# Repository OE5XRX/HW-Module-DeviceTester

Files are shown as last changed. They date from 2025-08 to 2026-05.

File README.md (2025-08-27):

# HW-Module-DeviceTester

## License

This project is licensed under [CERN-OHL-S-2.0](https://choosealicense.com/licenses/cern-ohl-s-2.0/).

## Badges

<br>
<br>
<br>
<br>
<br>

## Contact

OE5XRX Amateur Radio Club<br>
🌐 https://oe5xrx.org<br>
✉️ info@oe5xrx.org<br>

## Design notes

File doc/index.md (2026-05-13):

---
title: Device Tester
nav_order: 1
parent: Hardware
description: Bringup und Test-Board für die OE5XRX-Hardware-Module — Standalone-Modul-Test, BusBoard-Test ohne eigene Versorgung, CM4-Flash via rpiboot.
---

# Device Tester PCB

<table>
  <tr><th>Top</th><th>Bottom</th></tr>
  <tr>
    <td>top</td>
    <td>bottom</td>
  </tr>
</table>

## Übersicht

Universelles Bringup- und Test-Board für alle OE5XRX-Hardware-Module. Es hat zwei voneinander unabhängige Steckverbinder-Seiten und kombiniert sie mit USB-C-PC-Anschlüssen, einer +12V-Schraubterminal-Quelle und einem 4-Pin-Flash-Header für CM4-rpiboot:

- **Device-Tester-Seite** (`J203`, männlicher PCN10-Stecker — wie ein BusBoard-Slot): Hier wird ein zu testendes Modul (PowerBoard, CM4Carrier, FM-Transceiver etc.) eingesteckt. Das Modul wird vom DeviceTester aus mit Strom versorgt — USB-C `J201` bringt +5V_A; Phoenix-Schraubterminal `J101` bringt +12V (für Module die echte +12V brauchen, z.B. FM-Modul mit SA818-TX-Spitzen).
- **Bus-Tester-Seite** (`J302`, weibliche PCN10C-Buchse — wie ein Modul): Hier wird ein zu testendes BusBoard angesteckt. USB-C `J301` bringt +5V_B und kann über Jumper `J303` an die Bus-Tester-Seite durchgereicht werden, sodass das BusBoard ohne eigenes PowerBoard betrieben werden kann.
- **CM4 flashen**: Über den 4-Pin Flash-Header `J202` werden die beiden Bus-Pins `nRPIBOOT` und `USB_OTG_ID` manuell per Jumper auf die richtigen Pegel gezogen — siehe ["CM4 flashen"](#cm4-flashen) unten.

Die zwei +5V-Rails (`+5V_A` Device-Seite, `+5V_B` Bus-Seite) sind elektrisch entkoppelt, damit kein Backfeed zwischen den Test-Kontexten passiert.

## Block-Diagramm

```mermaid
flowchart LR
    USBCa["USB-C J201<br/>(Device-Seite)"] -->|"+5V_A"| RailA[/+5V_A/]
    Phoenix["Schraubterminal J101<br/>+12V"] --> Rail12[/+12V/]
    USBCb["USB-C J301<br/>(Bus-Seite)"] -->|"+5V_B"| RailB[/+5V_B/]

    RailA --> J203["J203 PCN10-20P (male)<br/>Device Tester Connector"]
    Rail12 --> J203
    RailA --> J202["J202 4-Pin Flash-Header<br/>(rpiboot Jumper)"]

    RailB -.->|"J303 Jumper<br/>(optional)"| J302
    J302["J302 PCN10C-20S (female)<br/>Bus Tester Connector"]

    J203 -->|"USB+/-"| USBCa
    J302 -->|"USB+/-"| USBCb
    J202 -.->|"nRPIBOOT, USB_OTG_ID"| J203

    DUT[Device Under Test<br/>Modul] -.->|"steckt in"| J203
    BB[BusBoard Under Test] -.->|"steckt in"| J302
```

## Steckverbinder

| Bezeichner | Typ | Funktion |
| --- | --- | --- |
| **J101** | Phoenix MKDS-1,5-2 5.08 mm Schraubterminal (2-Pin) | +12V-Eingang. Nötig für Module die echte +12V brauchen (z.B. SA818-TX). |
| **J201** | USB-C 2.0 (G-Switch GT-USB-7010ASV) | Device-Seite. +5V_A-Versorgung und USB-Datenanschluss für den DUT in `J203`. |
| **J202** | 4-Pin Stiftleiste 2.54 mm | Flash-Header: GND / nRPIBOOT / USB_OTG_ID / +5V_A. Silkscreen-beschriftet. |
| **J203** | Hirose **PCN10-20P-2.54DS** (männlich, 2×10) | "Device Tester Connector" — Slot in den der DUT eingesetzt wird. Pinbelegung entspricht der BusBoard-Slot-Seite. |
| **J301** | USB-C 2.0 (G-Switch GT-USB-7010ASV) | Bus-Seite. +5V_B-Versorgung und USB-Datenanschluss für eine angeschlossene BusBoard. |
| **J302** | Hirose **PCN10C-20S-2.54DS** (weiblich, 2×10) | "Bus Tester Connector" — Buchse die in einen BusBoard-Slot gesteckt wird. Pinbelegung wie ein normaler Modul-Stecker. |
| **J303** | 2-Pin Stiftleiste 2.54 mm | Jumper: schließt `+5V_B` auf die `+5V`-Pins von `J302`. Bei externer Bus-Versorgung **offen** lassen. |

## Versorgung (drei Rails)

| Rail | Quelle | Funktion | Status-LED |
| ---- | --- | --- | --- |
| **+12V** | Schraubterminal `J101` | Speist den DUT in `J203` (+12V-Pins des PCN10-Steckers) | `D101` |
| **+5V_A** | USB-C `J201` (VBUS) | Speist `J203` (+5V-Pins) und `J202` Pin 4. Auch USB-Daten zum DUT laufen über `J201`. | `D201` |
| **+5V_B** | USB-C `J301` (VBUS) | Speist `J302` (+5V-Pins) **nur wenn Jumper `J303` geschlossen**. USB-Daten zur BusBoard laufen über `J301`. | `D301` |

Hinweis: `+12V` (`J101`) und `+5V_A` (`J201` VBUS) sind unabhängige Quellen. Beide können zusammen oder einzeln versorgt werden — der DUT zieht aus jeder Quelle was er braucht.

## CM4 flashen

Der CM4-Carrier hat keinen eigenen rpiboot-Jumper — beide Steuersignale (`nRPIBOOT` und `USB_OTG_ID`) sind auf den Bus-Stecker geführt. Hier am DeviceTester werden sie über den 4-Pin Flash-Header `J202` manuell per Jumper auf die korrekten Pegel gezogen:

| Pin | Signal |
|----:|---|
| 1 | GND |
| 2 | `nRPIBOOT` (geht via `J203 b2` zum CM4) |
| 3 | `USB_OTG_ID` (geht via `J203 b3` zum CM4) |
| 4 | +5V_A |

Jumper-Konfiguration für rpiboot-Mode:

- **Pin 1 ↔ 2** (GND ↔ nRPIBOOT) — versetzt den CM4 nach Power-Up in den USB-Boot-Modus.
- **Pin 3 ↔ 4** (USB_OTG_ID ↔ +5V_A) — schaltet die CM4-USB-Schnittstelle in den Device-Mode (PC = Host, CM4 = Peripheral).

Ablauf:

1. CM4 in den [CM4-Carrier](../HW-Module-CM4Carrier/) einsetzen, Carrier in den DeviceTester `J203` einstecken.
2. Beide Jumper auf `J202` setzen (1↔2 + 3↔4).
3. `J201` USB-C mit dem PC verbinden.
4. `rpiboot` auf dem PC starten — der CM4 erscheint als USB-Mass-Storage-Device (eMMC-Variante).
5. Nach dem Flashen: **beide Jumper wieder abziehen**, sonst bleibt der Carrier beim nächsten Power-Up im rpiboot-Mode hängen statt regulär zu booten.

## Test-Workflows

### 1. DUT-Test (Standalone-Modul-Bringup)

Use Case: ein einzelnes Modul (z.B. FM-Transceiver oder PowerBoard) **ohne** vollständige Remote-Station-Umgebung testen oder debuggen.

1. Modul in `J203` (Device Tester Connector) einsetzen.
2. +12V an `J101` anschließen falls das Modul +12V braucht (z.B. FM-Transceiver wegen SA818).
3. `J201` USB-C mit dem PC verbinden — versorgt das Modul mit +5V_A und macht dessen USB-Datenleitungen am PC sichtbar.
4. Tests/Bringup wie in der Doku des jeweiligen Moduls beschrieben (siehe `Bringup`-Sektionen der Modul-Docs).

### 2. CM4 flashen (rpiboot)

Siehe Sektion ["CM4 flashen"](#cm4-flashen) oben.

### 3. BusBoard-Test ohne eigene Versorgung

Use Case: eine BusBoard testen ohne komplettes PowerBoard angeschlossen zu haben — der DeviceTester speist das BusBoard direkt aus USB-C.

1. DeviceTester via `J302` (Bus Tester Connector — die weibliche Buchse) in einen freien Slot der zu testenden BusBoard stecken.
2. **`J303` Jumper schließen** — verbindet `+5V_B` mit den `+5V`-Pins von `J302`, sodass das BusBoard aus dem USB-C versorgt wird.
3. `J301` USB-C mit dem PC verbinden.
4. Falls das BusBoard ihr eigenes PowerBoard hat → `J303` Jumper **offen** lassen, sonst gibt's Backfeed-Risiko zwischen den zwei +5V-Quellen.

## Bringup des DeviceTester selbst

Nach Bestückung:

1. **+12V-Sanity:** Strombegrenztes Labornetzgerät (12 V / 100 mA) an `J101` anschließen → `D101` muss leuchten. Strom < 5 mA erwartet (nur LED + ihre Vorwiderstände).
2. **+5V_A-Sanity:** USB-C-Kabel an `J201` und einen USB-Host (PC oder Powerbank) → `D201` muss leuchten.
3. **+5V_B-Sanity:** USB-C-Kabel an `J301` → `D301` muss leuchten.
4. **+12V am DUT-Konnektor:** zwischen `J203`-Pins messen — die +12V-Pins müssen die Eingangsspannung zeigen.
5. **+5V_B-Isolation:** `J303` offen, `J301` versorgt — zwischen `J302`-Pin-+5V und GND messen → muss **0 V** zeigen. `J303` schließen → +5V_B muss durchschlagen.

## Verwandte Module

- [BusBoard](../HW-Module-BusBoard/) — kann via Bus-Tester-Seite (`J302`) ohne eigenes PowerBoard getestet werden.
- [CM4 Carrier](../HW-Module-CM4Carrier/) — wird via Device-Tester-Seite (`J203`) geflasht; rpiboot-Logik im DeviceTester (`J202`).
- [PowerBoard](../HW-Module-PowerBoard/) — kann standalone via Device-Tester-Seite (`J203` + Phoenix `J101` für +12V) getestet werden.
- [FM Transceiver](../HW-Module-FMTransceiver/) — Standalone-Bringup via Device-Tester-Seite (braucht beide Quellen: USB-C für USB + +5V, Phoenix für +12V).

## Daten

- [Schaltplan]({{ site.data.project.name }}-schematic.pdf)
- [BOM]({{ site.data.project.name }}-bom.html)
- [iBOM]({{ site.data.project.name }}-ibom.html)
- [JLCPCB fabrication & stencil](JLCPCB/{{ site.data.project.name }}-_JLCPCB_compress.zip)
- [JLCPCB Bom](JLCPCB/{{ site.data.project.name }}_bom_jlc.csv)
- [JLCPCB Pick&Place](JLCPCB/{{ site.data.project.name }}_cpl_jlc.csv)

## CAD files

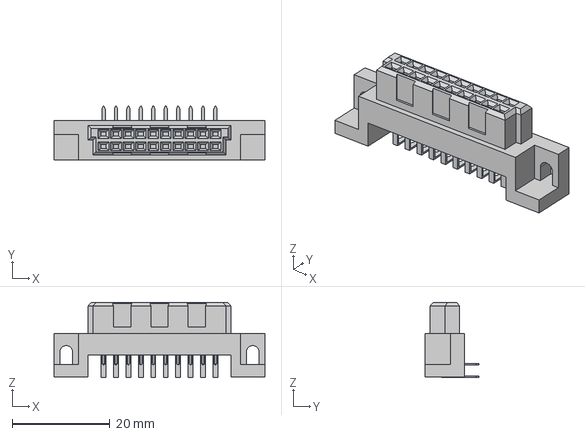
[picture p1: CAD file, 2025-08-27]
3d-models/PCN10C-20S-2.54DS.stp
43.1 x 11.0 x 15.3 mm

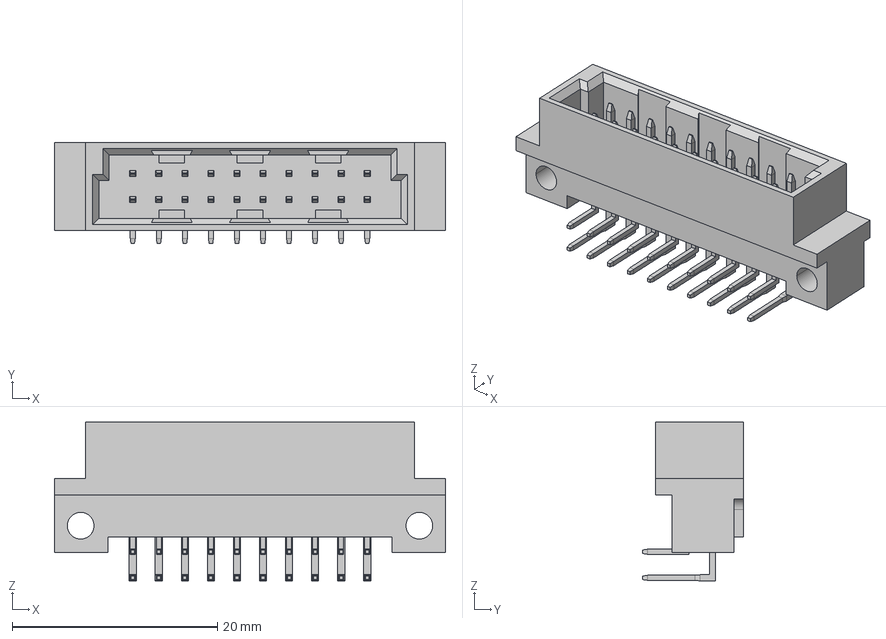
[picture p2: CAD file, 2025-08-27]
3d-models/PCN10-20P-2.54DS.stp
38.1 x 9.85 x 15.5 mm

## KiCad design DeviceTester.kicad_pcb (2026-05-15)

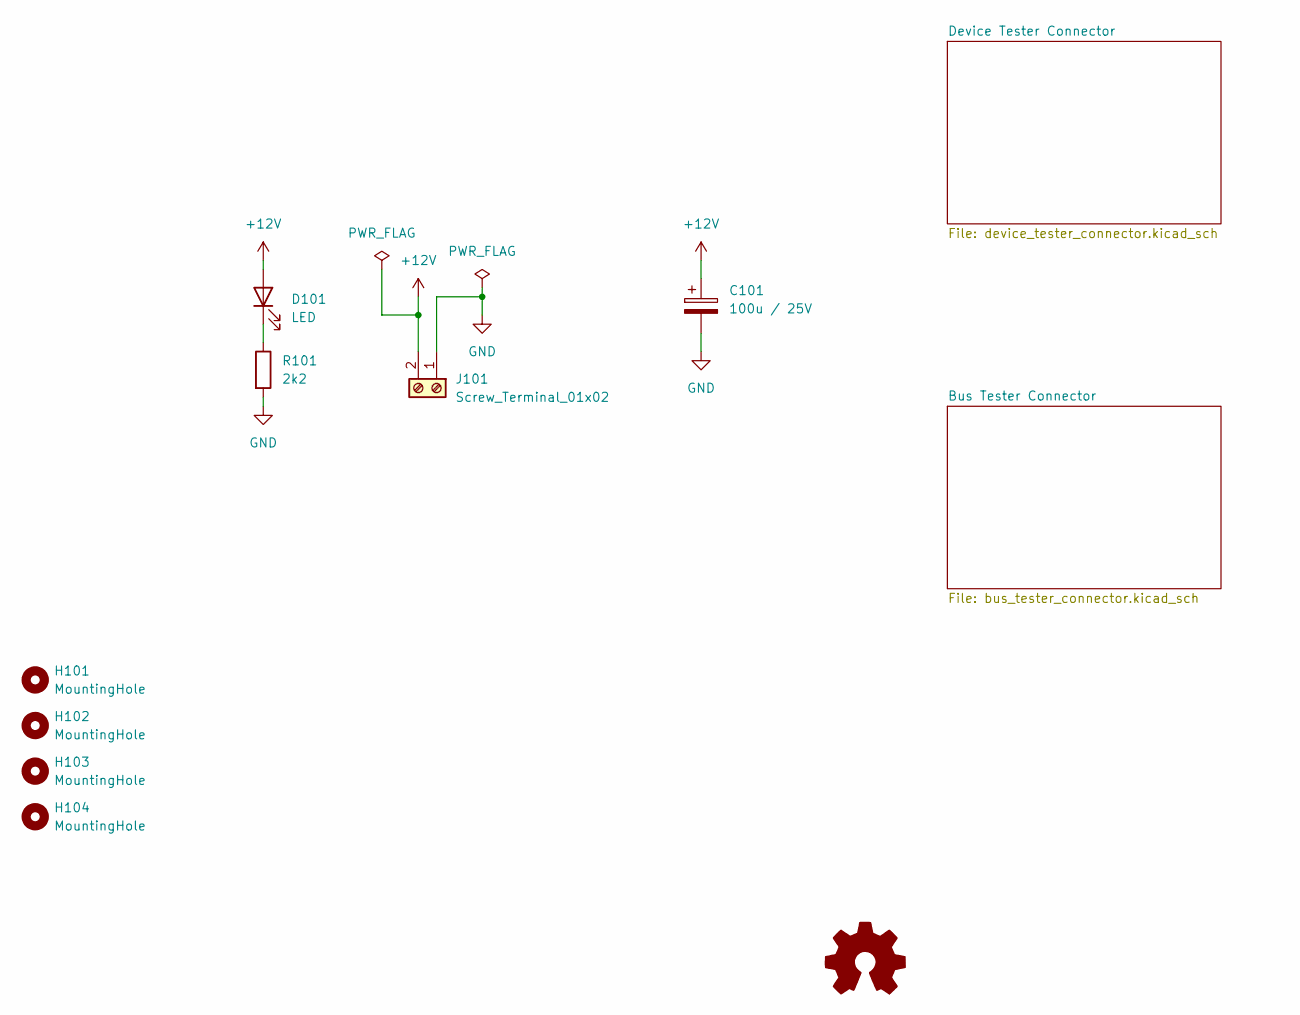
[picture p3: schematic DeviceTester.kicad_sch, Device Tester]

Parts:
C101: 100u / 25V; CP_EIA-7343-43_Kemet-X; LCSC C132558
D101: LED; LED_0805_2012Metric; LCSC C84256
H101, H102, H103, H104: MountingHole; MountingHole_3.2mm_M3
J101: Screw_Terminal_01x02; TerminalBlock_Phoenix_MKDS-1,5-2-5.08_1x02_P5.08mm_Horizont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; LCSC C5349557
R101: 2k2; R_0805_2012Metric; LCSC C17520

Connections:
+12V: C101.1, D101.2 (A), J101.2; also elsewhere on the board
GND: C101.2, J101.1, R101.2; also elsewhere on the board
unnamed: D101.1 (K), R101.1

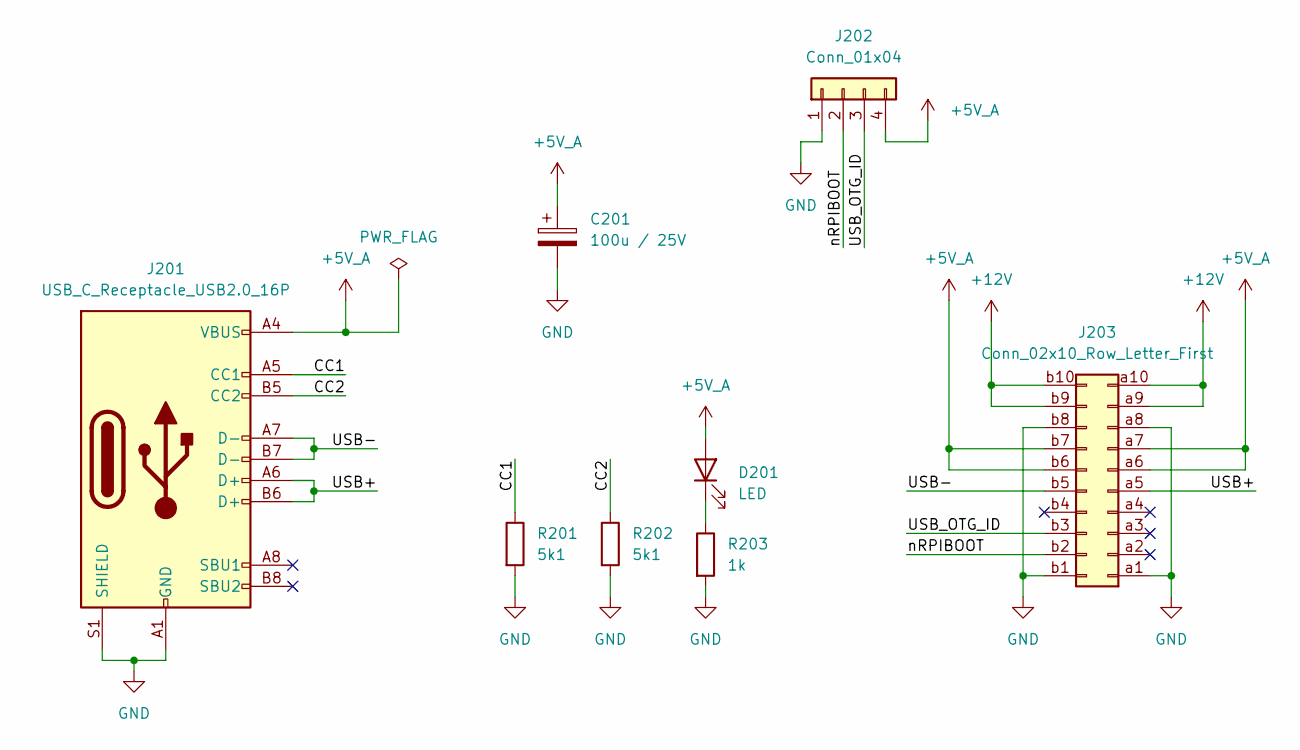
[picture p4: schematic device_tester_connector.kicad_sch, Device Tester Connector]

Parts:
C201: 100u / 25V; CP_EIA-7343-43_Kemet-X; LCSC C132558
D201: LED; LED_0805_2012Metric; LCSC C84256
J201: USB_C_Receptacle_USB2.0_16P; USB_C_Receptacle_G-Switch_GT-USB-7010ASV; LCSC C2988369
J202: Conn_01x04; PinHeader_1x04_P2.54mm_Vertical; LCSC C2691448
J203: Conn_02x10_Row_Letter_First; PCN10-20P-2.54DS; MOUSER 798-PCN1020P254DS72
R201, R202: 5k1; R_0805_2012Metric; LCSC C27834
R203: 1k; R_0805_2012Metric; LCSC C17513

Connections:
+5V_A: C201.1, D201.2 (A), J201.A4 (VBUS), J201.A9 (VBUS), J201.B4 (VBUS), J201.B9 (VBUS), J202.4, J203.a6, J203.a7, J203.b6, J203.b7
+12V: J203.a9, J203.a10, J203.b9, J203.b10; also elsewhere on the board
/Device Tester Connector/CC1: J201.A5 (CC1), R201.1
/Device Tester Connector/CC2: J201.B5 (CC2), R202.1
/Device Tester Connector/USB+: J201.A6 (D+), J201.B6 (D+), J203.a5
/Device Tester Connector/USB-: J201.A7 (D-), J201.B7 (D-), J203.b5
/Device Tester Connector/USB_OTG_ID: J202.3, J203.b3
/Device Tester Connector/nRPIBOOT: J202.2, J203.b2
GND: C201.2, J201.A1 (GND), J201.A12 (GND), J201.B1 (GND), J201.B12 (GND), J201.S1 (SHIELD), J202.1, J203.a1, J203.a8, J203.b1, J203.b8, R201.2, R202.2, R203.2; also elsewhere on the board
unnamed: D201.1 (K), R203.1

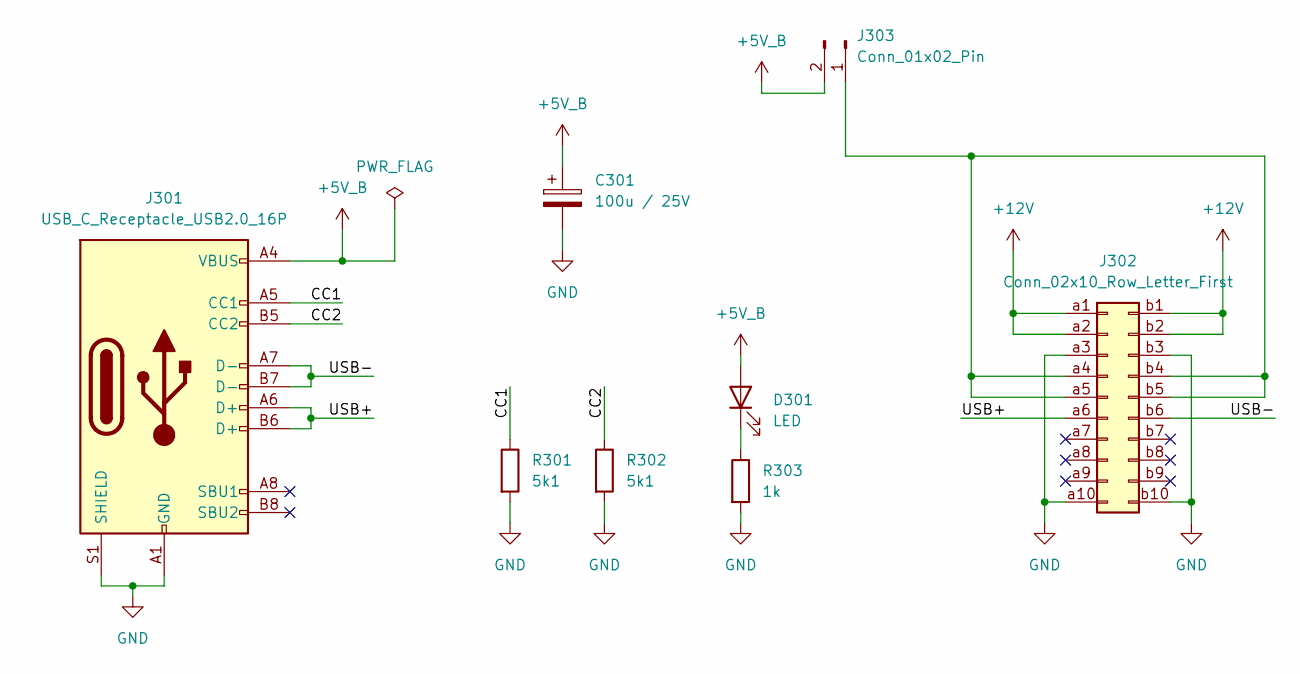
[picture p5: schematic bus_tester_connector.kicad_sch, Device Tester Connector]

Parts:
C301: 100u / 25V; CP_EIA-7343-43_Kemet-X; LCSC C132558
D301: LED; LED_0805_2012Metric; LCSC C84256
J301: USB_C_Receptacle_USB2.0_16P; USB_C_Receptacle_G-Switch_GT-USB-7010ASV; LCSC C2988369
J302: Conn_02x10_Row_Letter_First; PCN10C-20S-2.54DS; MOUSER 798-PCN10C20S254DS72
J303: Conn_01x02_Pin; PinHeader_1x02_P2.54mm_Vertical
R301, R302: 5k1; R_0805_2012Metric; LCSC C27834
R303: 1k; R_0805_2012Metric; LCSC C17513

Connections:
+5V_B: C301.1, D301.2 (A), J301.A4 (VBUS), J301.A9 (VBUS), J301.B4 (VBUS), J301.B9 (VBUS), J303.2
+12V: J302.a1, J302.a2, J302.b1, J302.b2; also elsewhere on the board
/Bus Tester Connector/CC1: J301.A5 (CC1), R301.1
/Bus Tester Connector/CC2: J301.B5 (CC2), R302.1
/Bus Tester Connector/USB+: J301.A6 (D+), J301.B6 (D+), J302.a6
/Bus Tester Connector/USB-: J301.A7 (D-), J301.B7 (D-), J302.b6
GND: C301.2, J301.A1 (GND), J301.A12 (GND), J301.B1 (GND), J301.B12 (GND), J301.S1 (SHIELD), J302.a3, J302.a10, J302.b3, J302.b10, R301.2, R302.2, R303.2; also elsewhere on the board
unnamed: D301.1 (K), R303.1
unnamed: J302.a4, J302.a5, J302.b4, J302.b5, J303.1

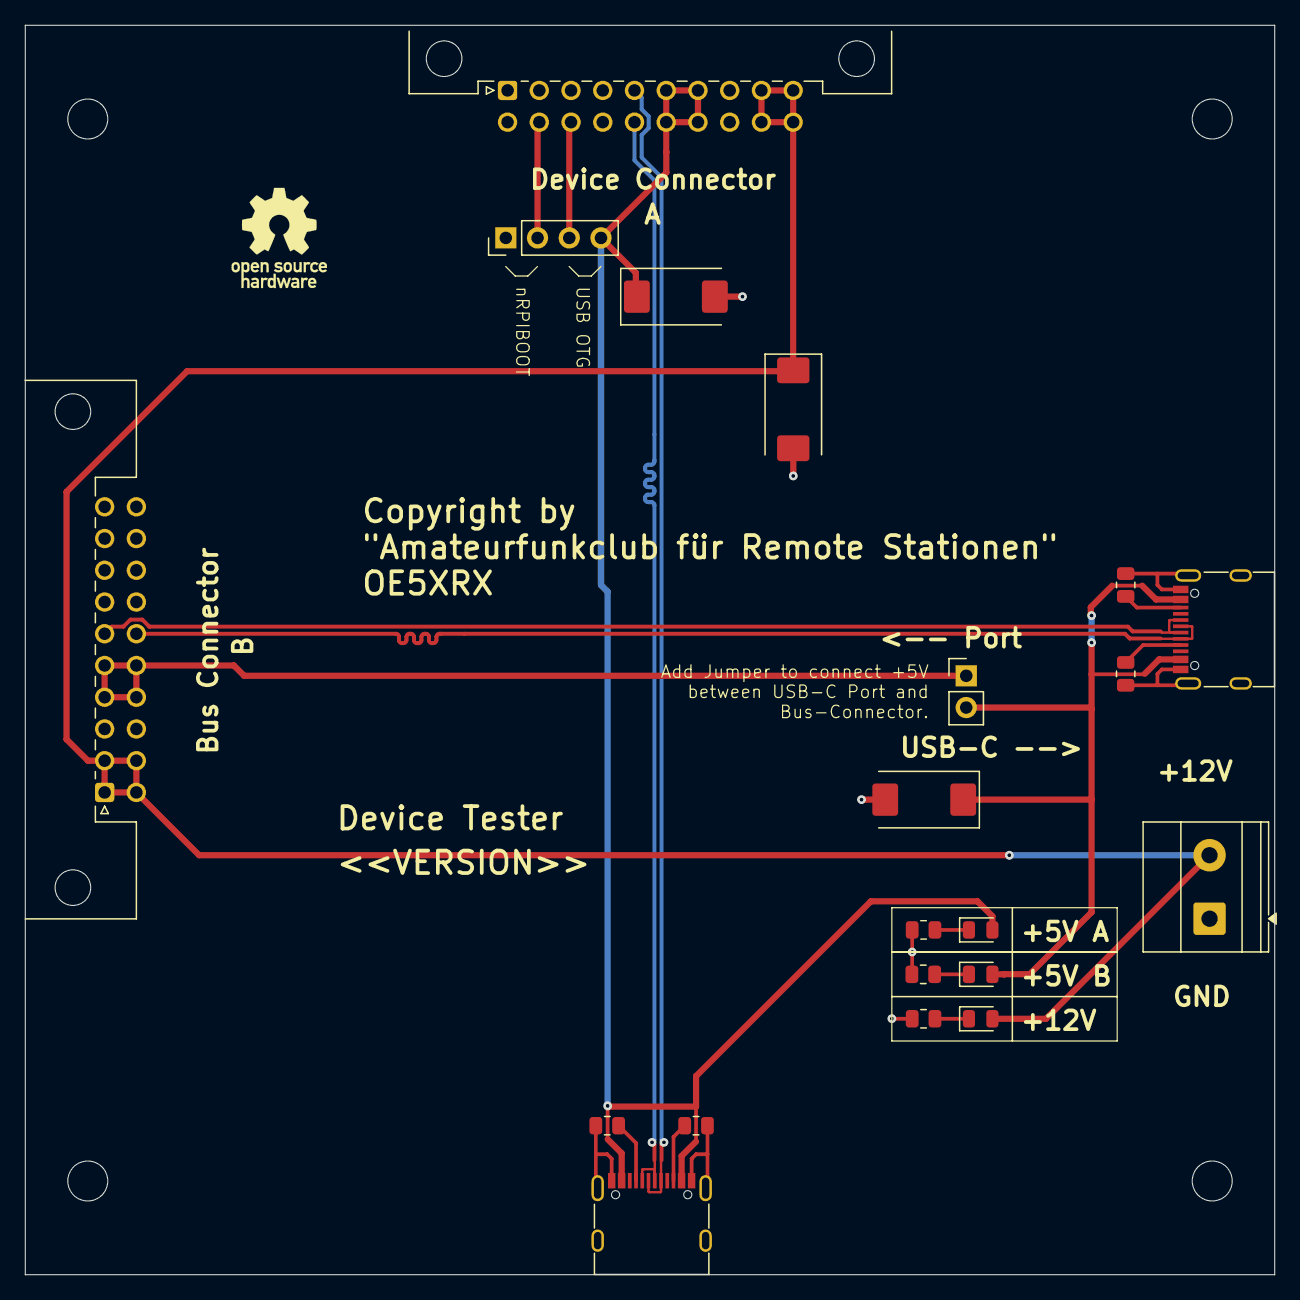
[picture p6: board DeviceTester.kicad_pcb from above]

Board: 4 copper layers, 100.0 x 100.0 mm, 24 parts (0 on the bottom side), 18 nets.

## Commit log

2025-08-27 setup project
    [PCN10-20P-2.54DS.stp, PCN10C-20S-2.54DS.stp, bus_tester_connector.kicad_sch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]
2025-09-05 🔄 synced local '.github/workflows/create-debug-docs.yaml' with remote '.github/workflows/create-debug-docs.yaml'
2025-09-05 🔄 created local 'doc/_config.yml' from remote 'doc/_config.yml'
2025-09-05 🔄 created local 'doc/favicon.ico' from remote 'doc/favicon.ico'
2025-09-05 🔄 created local 'Gemfile' from remote 'Gemfile'
2026-05-12 rename(kicad): main.kicad_* → DeviceTester.kicad_*
    [DeviceTester.kicad_pcb, DeviceTester.kicad_sch]
2026-05-13 docs: rewrite DeviceTester index.md with full architecture overview
    Adds:
    - 1-sentence description front-matter
    - Übersicht: two-sided board (Device-Tester male PCN10 / Bus-Tester
    female PCN10C) + 3 power rails + flash header for rpiboot
    - Mermaid block diagram showing both halves + flash header + DUT/BB
    - Steckverbinder-Tabelle: all 7 J-refs (Phoenix, 2× USB-C, 4-pin Flash,
    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
2026-05-13 Address Copilot review (round 2)
    - Normalize 'Bring-up' → 'Bringup' throughout (6 occurrences) for
    consistency with PowerBoard, BusBoard, CM4Carrier, and FM-Transceiver
    docs which all use the no-hyphen spelling.
2026-05-15 chore: migrate <<HASH>> placeholder to <<VERSION>> (#4)
    Aligns the KiCad title-block placeholder with the new versioning concept
    documented at oe5xrx.org/docs/remote-station/hardware/versioning/.
    The placeholder is substituted at CI time:
    - Release build: v1.5 → "1.5" (semver only, no `v`, no SHA)
    - Debug build: "BETA-<short-commit>"
    No electrical or layout change — pure text replacement on the title-block
    silkscreen text. Requires HW-Module-CI feat/version-placeholder
    (OE5XRX/HW-Module-CI#4) to be merged first; otherwise CI substitutes
    the old <<HASH>> token and leaves the new <<VERSION>> string literal
    in the title block until the CI side catches up.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
    [DeviceTester.kicad_pcb, DeviceTester.kicad_sch, bus_tester_connector.kicad_sch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]
2026-11-08 feat: add 'Slot' design variant for enclosure slot operation (#6)
    Marks J201, J202, J203, C201, R201-R203 and D201 as do-not-populate
    in the new 'Slot' variant so the board fits a station slot.

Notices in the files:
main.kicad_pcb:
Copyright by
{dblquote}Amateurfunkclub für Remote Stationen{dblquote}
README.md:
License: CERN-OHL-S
